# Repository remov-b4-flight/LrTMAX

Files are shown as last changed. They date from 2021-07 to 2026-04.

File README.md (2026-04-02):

# LrTMAX
Adobe Lightroom MIDI Developer Controller project (STM32F072Cx based)  
LrTMAX MIDI controller is formed by embedded hardware circuit board and its firmware.  
It used with [MIDI2LR](https://github.com/rsjaffe/MIDI2LR) software,  
You can control development parameters on RAW/JPEG photos.  
## Video(in brother project LrE-6)
  
detailed Video on [YouTube (LrE-6)](https://www.youtube.com/watch?v=oeDpP1sG9_Y)  
## Photo
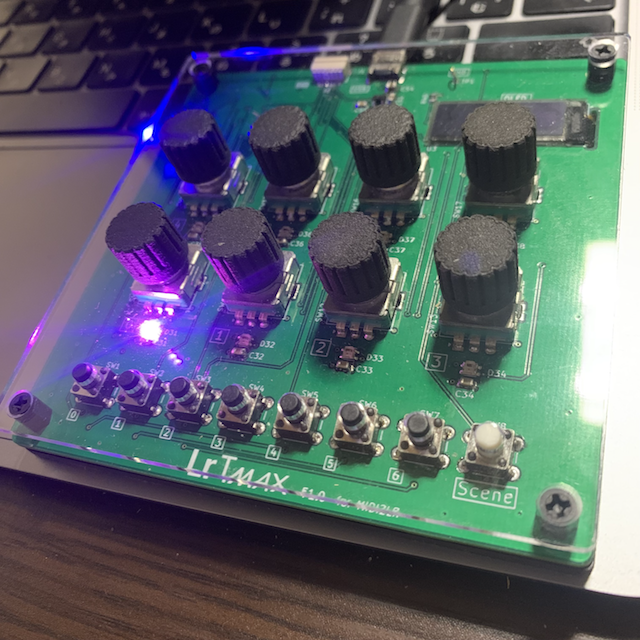
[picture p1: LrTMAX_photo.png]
  
LrTMAX is near to [LrE-6](https://github.com/remov-b4-flight/LrE-6)  
Information related Build,Configure & Use are exists on wiki.  
***
"Lightroom Classic" is Registerd Trademark of Adobe Corporation.

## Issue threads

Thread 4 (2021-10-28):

connection bitmap の描画

remov-b4-flight, 2021-10-28:
connection bitmapの描画、バージョン番号の部分の描画が正しく無い場合がある。
毎度違うパターンでおかしい。正しく描いている時もある。
絵の部分は正常

remov-b4-flight, 2021-10-29:
個別に描かせると正常

remov-b4-flight, 2021-11-01:
Still issue exists

remov-b4-flight, 2021-11-01:
明が暗に転ぶドットばかり
暗が明に転ぶドットはない。
絵の部分は正常

remov-b4-flight, 2021-11-02:
> 個別に描かせると正常

そういう訳でもないみたい。

remov-b4-flight, 2021-11-02:
Issue seems to be fixed.

Closed 2021-11-02.

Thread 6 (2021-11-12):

エンコーダーの動作が一瞬逆向きになる

remov-b4-flight, 2021-11-12:
まだエンコーダー0でしか試してないが動かした向きと逆に認識されてしまう場合がある

remov-b4-flight, 2021-11-13:
エンコーダー波形見るとチャッタリングしている。22nFでは除去仕切れないか。

remov-b4-flight, 2021-11-14:
エンコーダー0だけ100nFに交換して様子見。

remov-b4-flight, 2021-11-14:
Fixed in 0.55

remov-b4-flight, 2022-09-25:
チャタリングではなくエンコーダの機械的損耗でどちらのクリックに止まるか不安定な区間があり、結果短時間で信号の遷移が起こってしまう。

remov-b4-flight, 2022-09-25:
Fixed by 0.61

remov-b4-flight, 2022-09-25:
> エンコーダー0だけ100nFに交換して様子見。

反応悪くなる副作用あるので戻す。

Closed 2021-11-14.

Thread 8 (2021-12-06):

「現像」タブに移ると操作を反映しない

remov-b4-flight, 2021-12-06:
シーンスイッチで現像に移るよう設定すると移ったあと直後もしくは数十回の操作で操作を反映しなくなる。

remov-b4-flight, 2021-12-06:
MIDI2LR.appの設定で「現像に移る」を「未割り当て」に設定すれば停止しなくなるとでMIDI2LR側が問題ある可能性がある。

remov-b4-flight, 2021-12-06:
LEDとOLEDの表示には操作が反映されている。

remov-b4-flight, 2021-12-06:
USBの抜き差しまで機能が回復することはない。

remov-b4-flight, 2021-12-06:
開発マシンでMIDIMonitor.app使うとシーン切り替えボタンの後もMIDIメッセージを送り続けている。

remov-b4-flight, 2021-12-11:
MIDI2LR.appで「Lightroomへ送信を停止」すると、止まらない。やはりMIDI2LR側の問題か。

remov-b4-flight, 2021-12-11:
> MIDI2LR.appの設定で「現像に移る」を「未割り当て」に設定すれば停止しなくなるのでMIDI2LR側が問題ある可能性がある。

「未割り当て」でも停止してしまう。

remov-b4-flight, 2021-12-17:
Not issue on LrTMAX.

remov-b4-flight, 2021-12-30:
AKAI Synthstation25では起きないので、LrTMAXの何かが原因っぽい。

remov-b4-flight, 2021-12-31:
CCチャネル番号がNRPNの設定シーケンスで使用するチャンネルと被っているので40オフセットをつけて空き番号の空間に移動する。

remov-b4-flight, 2022-01-04:
Problem still exists.

remov-b4-flight, 2022-01-08:
0.57-4 seems to be fixed.

remov-b4-flight, 2022-01-10:
SynthStation25のMIDI descriptorをコピーしたら解決したようだ。

remov-b4-flight, 2023-06-29:
nanooKontrol2ベースにしたら再発した(?)

remov-b4-flight, 2023-06-29:
> USBの抜き差しまで機能が回復することはない。

ファームウェアリブートまで機能が回復する事はない。

remov-b4-flight, 2023-07-01:
アクティビティモニター 反応ある間は送信パケットの数値が操作とともに上がっていくが、症状が出ると上がらなくなる。

remov-b4-flight, 2023-07-01:
> アクティビティモニター 反応ある間は送信パケットの数値が操作とともに上がっていくが、症状が出ると上がらなくなる。

と、言うことは問題はMIDI2LR.Appか。

remov-b4-flight, 2023-07-03:
MIDI2LR.app ソース解析の結果、
CC チャンネル 6,38,98,99は
NRPNの処理用に個別の判断の判断があるため、使用を避ける。
CC 40(decimal)をシーン0、エンコーダ0のチャンネルとする。

remov-b4-flight, 2023-07-04:
問題が発生する「部分補正 テクスチャ」と「部分補正 明瞭度」についてもマスクを作る前なら問題なく何回でも操作できる。

remov-b4-flight, 2023-07-04:
> 問題が発生する「部分補正 テクスチャ」と「部分補正 明瞭度」についてもマスクを作る前なら問題なく何回でも操作できる。

ということはLrTMAXには何の問題もない(?)

remov-b4-flight, 2023-07-18:
現像調整をしているファイルに移るとCCコマンドを受信して現在値を反映するが、これを受信した後反映しなくなる

remov-b4-flight, 2023-07-18:
usbd_midi.c を見ると MidiRx()を呼んだ後、
USBD_LL_PrepareReceive()を呼んでいる。
この部分に時間がかかる事は障害になると考え、
Midi_Rx内でキューイングを行うようにした。

remov-b4-flight, 2023-07-18:
キューイングされたデータはEmulate MIDI 内で処理して、
MIDI_CC_Value[] に反映している事までを確認した。

remov-b4-flight, 2023-07-18:
ただし、MIDI_CC_Value[] の反映を行ったあと、送信データが反映されない。か、ピッチベンドとして解釈されてしまう。

remov-b4-flight, 2023-07-19:
MIDI2LR.Appからの受信で何か起きるようだ。
ブランチMidiRXで作業中

remov-b4-flight, 2023-07-19:
データを受信したあと、全く送信していないわけでは無く、操作に応じた送信自体は続いている。

remov-b4-flight, 2023-07-19:
調整が一つなら止まらない。4つは確実に止まってしまう。

remov-b4-flight, 2023-07-22:
現像タブ上でも、ゆっくりした操作なら、止まらない。
ライブラリタブなら止まらない。

remov-b4-flight, 2023-07-23:
0.67で部分的に解決

remov-b4-flight, 2023-07-27:
0.67の解決はプロジェクト全体に-Ofastを指定さた物だったが
エンコーダーの向きが逆開店に認識される副作用が発生する様だ。
-O3なら発生しない模様。

remov-b4-flight, 2023-07-28:
> 0.67の解決はプロジェクト全体に-Ofastを指定さた物だったが
> エンコーダーの向きが逆開店に認識される副作用が発生する様だ。
> -O3なら発生しない模様。

-O3でも発生してしまう。-O2は出ない

remov-b4-flight, 2023-07-31:
#19 の問題を解決したら逆向きは軽減した 最適化は-O2で固定

remov-b4-flight, 2023-08-19:
#19 の根本的解決でキューイングを改良したのでこのissueに関してもすこしはよくなっている事を期待する。

remov-b4-flight, 2023-08-19:
現像ずみ写真のコレクションをカーソルキーで辿っていっても止まらない。
エンコーダーの操作でのみ停止する。

remov-b4-flight, 2023-08-19:
受信しつつでも送信はしている様だ。

remov-b4-flight, 2023-08-19:
ゆっくり操作、特に現像履歴がアクティブになった後まで待ってエンコーダを動かすと、止まらない。

remov-b4-flight, 2023-08-21:
自家ビルドしたMIDI2LR Appでログとかブレークポイントを張った結果、現象が起きている時はMidiReceiverに制御が来ていない、
juicerで止まっている

remov-b4-flight, 2023-08-25:
0.69で止まらなくなった。対策完了？

Closed 2023-08-25.

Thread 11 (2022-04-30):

CC78[64]なモードに入ってしまう。

remov-b4-flight, 2022-04-30:
突然 Control Channel=78 value=64しか送らないモードに入ってしまう。
きっかけは Scene0 ENC0の操作っぽい。 それ以降どの操作でもCC 78[64]を送るようだ。
電源再投入まで復帰せず。

remov-b4-flight, 2022-04-30:
そんなに頻繁な発生ではない。

remov-b4-flight, 2022-05-22:
CC[90]= 40というパターンもある。
OLEDの表示は正常。

Closed 2023-05-18.

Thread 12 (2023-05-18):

反応が無くなる

remov-b4-flight, 2023-05-18:
正常に操作していた後、しばらく放置しておくと
操作してもMIDI2LRアプリの反応がなくなる。
「再読み込み」で戻ってくる場合が殆どだが、戻ってこない場合もある。
macOSでのみ確認

remov-b4-flight, 2023-06-20:
場当たり的な対策としてSW1とSW8 (Undoと Scene)を同時押しする事でパワーオンリセット実行する様変更

remov-b4-flight, 2023-06-29:
#8 と原因同じかもしれないのでそちらで議論続ける。

Closed 2023-06-29.

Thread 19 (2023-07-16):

消耗でチャッターが酷くなる可能性

remov-b4-flight, 2023-07-16:
「次の写真-前の写真」に設定しているENC0だけチャッターと思われる逆方向に進んでしまう現象が頻発している。
- 問題はENC0だけ(使用頻度が極めて高い)
- ENC7に「次ー前」を設定しても現象出ない
- 問題は黒基板の運用機のみ。

remov-b4-flight, 2023-07-16:
#6 と重複かもしれない。

remov-b4-flight, 2023-07-16:
ENC0だけ33nFに替えてみる。

remov-b4-flight, 2023-07-16:
> ENC0だけ33nFに替えてみる。

確かにENC0だけチャッターがひどい波形になってる。

remov-b4-flight, 2023-07-17:
実験機(緑基板)も33nに交換する。

remov-b4-flight, 2023-07-18:
公開の回路図、BOMも33nで変更する。

remov-b4-flight, 2023-07-28:
チャッターも起きてはいるだろうが頻度が酷い。デバッグビルドでは軽減される(チャッターだけになる？)ので最適化が問題を引き起こしている可能性

remov-b4-flight, 2023-07-30:
TIM15のチャッター対策用のタイマーの設定値がひどい値だった。
0.67-11にて2mSに修正済み。

remov-b4-flight, 2023-08-01:
ENCの動きが止まった時にCC受信して、
値がMedian付近に居る時の方が
逆回転やチラつきなどの意図しない動きが少ない。

remov-b4-flight, 2023-08-12:
0.68で対応

remov-b4-flight, 2023-08-16:
MIDI2LRのソースより
変更量が正なら次へ、負なら前へ
`void LrIpcOut::MidiCmdCallback(rsj::MidiMessage mm)
略
                  if (const auto change {controls_model_.MeasureChange(mm)}; change > 0) {
                     SendCommand(a->second.first); /* turned clockwise */
                  }
                  else if (change < 0) {
                     SendCommand(a->second.second); /* turned counterclockwise */
                  }
略
`

remov-b4-flight, 2023-08-19:
やはりキューイングで止まっていた。
0.68-5で対応済み。

Closed 2023-08-19.

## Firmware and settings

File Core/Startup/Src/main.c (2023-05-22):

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
/* Includes ------------------------------------------------------------------*/
#include "main.h"
#include "usb_device.h"

/* USER CODE BEGIN Includes */
#include <stdbool.h>
#include "LrCommon.h"
#include "midi.h"
#include "led.h"
#include "bitcount.h"
#include "key_define.h"
#include "usbd_midi_if.h"
#include "ssd1306.h"
/* USER CODE END Includes */

/* USER CODE BEGIN PD */
#ifdef DEBUG
#define CONN_MSG_D	"%s %2x.%02xD"
#else
#define CONN_MSG	"%2x.%02x"
#endif

#define CC_MSG_3DG	"C%3d = %3d    S%1d"
#define CC_MSG_2DG	"Ch%1d = %3d    S%1d"
#define SPACE_CHAR  ' '

#define DFU_MSG	"DFU Bootloader."
#define SYSTEM_MEMORY	0x1FFFC800
#define SWMASK	0x0F
#define SW1_MASK	1
#define SW3_MASK	4
//! deine Key combination to invoke reset
#define RESET_KEY_PATTERN	0x81	//[Undo]+[Scene]

/* USER CODE END PD */

I2C_HandleTypeDef hi2c2;
DMA_HandleTypeDef hdma_i2c2_tx;

TIM_HandleTypeDef htim1;
TIM_HandleTypeDef htim3;
TIM_HandleTypeDef htim6;
TIM_HandleTypeDef htim7;
TIM_HandleTypeDef htim14;
TIM_HandleTypeDef htim15;
DMA_HandleTypeDef hdma_tim3_ch1_trig;

/* USER CODE BEGIN PV */

//! STM32 TIM3 instance handle
TIM_HandleTypeDef htim3;
extern	USBD_HandleTypeDef hUsbDeviceFS;
extern PCD_HandleTypeDef hpcd_USB_FS;
//! Lr**** USB connection state
uint8_t		LrState;
//! Lr**** Scene index
uint8_t	LrScene;
// keyboard variable
//! If true, ISR detected any Key/Encoder was moved.
bool		isKeyPressed;
//! Key pressed/released status set by timer key scanning.
KEYSCAN	Key_Stat;
//! In key scanning whether Line selected to read for key matrix.
uint8_t	Key_Line;
//! If true, MIDI event previous sent is switch. if false, it's encoder
bool		isPrev_sw;
#if 0
//! Bit masks for which bit of KEYSCAN variable acts as key.
uint32_t	MaskKey[SCENE_COUNT];
//! Bit masks for which bit of KEYSCAN variable acts as encoder.
uint32_t	MaskEnc[SCENE_COUNT];
#endif
// OLED variables
//! Flag set by timer ISR, It makes 'off' OLES contents.
bool 		Msg_Timer_Update;
//! Timer counter ticked by TIM7.
int32_t	Msg_Timer_Count;
//! If true Msg_Timer counting is enabled.
bool	Msg_Timer_Enable;
//! If true, Screen is cleared in main() that is determined on timer interrupt.
bool	Msg_Off_Flag;
//! If true, Screen is flashed by Msg_Buffer[] at main() function.
static	bool	isMsgFlash;
//! If true, frame_buffer[] contents flashes the screen.
static	bool	isRender;

// LED variables
//! If true, LEDs are flashed by LEDColor[] array.
bool	isLEDsendpulse;
//! Flag is set by timer ISR, It makes LED_Timer[] count up in main()
bool	LED_Timer_Update;

// Scene related
extern	KEY_DEFINE	keytable[SCENE_COUNT][DEFINES_PER_SCENE];
extern	char 		*scene_name[SCENE_COUNT];
extern	uint8_t	led_axis_table[DEFINES_PER_SCENE];

extern	uint8_t	LED_Scene[SCENE_COUNT][LED_COUNT];
extern	uint8_t	LEDColor[LED_COUNT];
extern	uint8_t	LEDTimer[LED_COUNT];

//! String message buffer of screen
extern char Msg_Buffer[MSG_LINES][MSG_WIDTH + 1];

// MIDI variables
//! MIDI CC message value for each channels.
uint8_t MIDI_CC_Value[SCENE_COUNT][ENC_COUNT];
//! keep previous sent 'Key On' note/channel for release message.
uint8_t prev_note;
//! Instance Handle of USB interface
extern USBD_HandleTypeDef *pInstance;

/* USER CODE END PV */

void SystemClock_Config(void);
static void MX_GPIO_Init(void);
static void MX_DMA_Init(void);
static void MX_TIM3_Init(void);
static void MX_TIM1_Init(void);
static void MX_TIM14_Init(void);
static void MX_I2C2_Init(void);
static void MX_TIM7_Init(void);
static void MX_TIM6_Init(void);
static void MX_TIM15_Init(void);
/* USER CODE BEGIN 0 */

/**
 * @brief jump into system memory (DFU bootloader)
 */
void Jump2SystemMemory() {
	void (*SysMemBootJump)(void);

	/*
	* Set system memory address.
	* For STM32F072, system memory is on 0x1FFFC800
	*/
	volatile uint32_t addr = SYSTEM_MEMORY;
	/**
	 * Stop all Interrupt source
	 */
	//TIM1
	TIM1->DIER = 0;
	TIM1->SR = 0;
	//TIM6
	TIM6->DIER = 0;
	TIM6->SR = 0;
	//TIM7
	TIM7->DIER = 0;
	TIM7->SR = 0;
	//EXTI
	EXTI->IMR = 0;
	EXTI->PR = 0;
	//DMA
	DMA1->IFCR = 0;
	//I2C2
	I2C2->ICR = 0;
	//USB
	USB->ISTR = 0;
	// Disable systick timer and reset it to default values
	SysTick->CTRL = 0;
	SysTick->LOAD = 0;
	SysTick->VAL = 0;

	// Re-map system memory to address 0x0000 0000 in address space
	SYSCFG->CFGR1 = 0x01;

	// Set jump memory location for system memory
	// Use address with 4 bytes offset which specifies jump location where program starts
	SysMemBootJump = (void (*)(void)) (*((uint32_t *)(addr + 4)));

	// Set main stack pointer.
	uint32_t msp = *(uint32_t *)addr;
	__set_MSP(msp);

	/**
	 * Call our function to jump to set location
	 * This will start system memory execution
	 */
	SysMemBootJump();
}

/**
 *	@brief	Mask all EXTI lines of encoders
 */
static void Stop_All_Encoders(){
	uint32_t temp = EXTI->IMR;
	temp &= 0xffff0000;
	EXTI->IMR = temp;
}

/**
 * @brief	Release all EXTI lines masked by StopAllEncoders()
 */
static void Start_All_Encoders(){
	uint32_t temp = EXTI->IMR;
	temp |= 0x0000ffff;
	EXTI->IMR = temp;
}

static inline void Start_MsgTimer(uint32_t tick){
	Msg_Off_Flag = false;
	Msg_Timer_Count = tick;
	Msg_Timer_Enable = true;
}

static inline void Msg_Print(){
	isMsgFlash = true;
}

/**
 * @brief Make MaskKey[],MaskRot[] from keytable[](in key_define.c)
 * @return false : there is some configuration error.
 */
static void	MakeMasks(){
#if 1
#else
	for(uint8_t scn = 0; scn < SCENE_COUNT; scn++){
		for(uint8_t bit = 0; bit < DEFINES_PER_SCENE; bit++){
			uint32_t	or_bit = (1 << bit);
			MaskKey[scn] |= (keytable[scn][bit].type == TYPE_SWITCH)?	or_bit : 0;
			MaskEnc[scn] |= (keytable[scn][bit].type == TYPE_ROTARY)?	or_bit : 0;
		}
	}
#endif
}
/**
 * @brief start/stop matrix L0-L3 control
 */
static void matrix_control(uint8_t control) {
	HAL_GPIO_WritePin(L0_GPIO_Port, L0_Pin, (control == Lr_MATRIX_START)? GPIO_PIN_SET : GPIO_PIN_RESET);
	HAL_GPIO_WritePin(L1_GPIO_Port, L1_Pin, GPIO_PIN_RESET);
	HAL_GPIO_WritePin(L2_GPIO_Port, L2_Pin, GPIO_PIN_RESET);
	HAL_GPIO_WritePin(L3_GPIO_Port, L3_Pin, GPIO_PIN_RESET);
}
/**
 *	@brief	Generate MIDI event and Send to host by User interaction.
 *	@return true : function processed any Key/Encoder event.
 *	@pre	isKeyPressed	any key is pressed or not
 *	@pre	Key_Stat		current key status
 */
static void EmulateMIDI() {
	//! USB MIDI message structure for send
	MIDI_EVENT	USBMIDI_TxEvent;

	if (isKeyPressed) {
		char 		msg_string[MSG_WIDTH + 1];
		uint8_t		bitpos = ntz32(Key_Stat.wd);
		uint32_t	rkey = (Key_Stat.wd);
		bool 		isKeyReport = false;

		if ( Key_Stat.wd & MASK_KEY ) { //Check Matrix switches
			//Send 'Note On' Event from key matrix
			uint8_t	note = (LrScene * NOTES_PER_SCENE) + bitpos;
			if (Key_Stat.wd == RESET_KEY_PATTERN) {
				HAL_NVIC_SystemReset();
			}else if (bitpos == SCENE_BIT) { //is [SCENE] switch pressed?
			   	//Move to next Scene.
				if((++LrScene) >= SCENE_COUNT){
					LrScene = Lr_SCENE0;
				}
				LED_SetScene(LrScene);
				strcpy(msg_string, scene_name[LrScene]);
			}else{
				LED_SetPulse(keytable[LrScene][bitpos].axis, keytable[LrScene][bitpos].color, keytable[LrScene][bitpos].period);
				sprintf(msg_string, "Note: %3d    S%1d", note, (LrScene % SCENE_COUNT) );
			}
			isKeyReport = true;

			//Print Message to OLED & LED
			if (keytable[LrScene][bitpos].message != NULL) {
				SSD1306_SetScreen(ON);

				strcpy(Msg_Buffer[0], keytable[LrScene][bitpos].message);
				strcpy(Msg_Buffer[1], msg_string);
				Msg_Print();

				Start_MsgTimer(MSG_TIMER_DEFAULT);
			}

			if (isKeyReport == true) {
				//Set 'Note ON
				USBMIDI_TxEvent.header = MIDI_NT_ON;
				USBMIDI_TxEvent.status = MIDI_NT_ON_S;
				USBMIDI_TxEvent.channel = note;
				USBMIDI_TxEvent.value = MIDI_NT_VELOCITY;

				prev_note = note;
				isPrev_sw = true;
			}
		}else if( Key_Stat.wd & MASK_ENC ) { //Check encoder's move
			//Send CC Event from encoder
			uint8_t axis = (bitpos - KEY_COUNT) / 2;
			uint8_t val = MIDI_CC_Value[LrScene][axis];
			uint8_t channel = CC_CH_OFFSET + (LrScene * CC_CH_PER_SCENE) + axis;

			USBMIDI_TxEvent.header = MIDI_CC_HEADER;
			USBMIDI_TxEvent.status = MIDI_CC_STATUS;
			USBMIDI_TxEvent.channel = channel;
			USBMIDI_TxEvent.value = val;

			isPrev_sw = false;

			//Print Message to OLED & LED
			if (keytable[LrScene][bitpos].message != NULL) {
				SSD1306_SetScreen(ON);
				sprintf(msg_string,
					((channel > 99)? CC_MSG_3DG : CC_MSG_2DG), channel, val, LrScene);
				strcpy(Msg_Buffer[0], keytable[LrScene][bitpos].message);
				strcpy(Msg_Buffer[1], msg_string);
				Msg_Print();

				Start_MsgTimer(MSG_TIMER_DEFAULT);
			}
			LED_SetPulse(keytable[LrScene][bitpos].axis, keytable[LrScene][bitpos].color, keytable[LrScene][bitpos].period);
			isKeyReport = true;

		} else if (isPrev_sw == true && rkey == 0) {// Switch is released
			//Send 'Note Off' Event
			USBMIDI_TxEvent.header = MIDI_NT_OFF;
			USBMIDI_TxEvent.status = MIDI_NT_OFF_S;
			USBMIDI_TxEvent.channel = prev_note;
			USBMIDI_TxEvent.value = MIDI_NT_VELOCITY;

			isKeyReport = true;
			isPrev_sw = false;
		}

		if (isKeyReport == true) {
			//Send MIDI event via USB
			USBD_LL_Transmit (pInstance, MIDI_IN_EP, (uint8_t *)&USBMIDI_TxEvent, MIDI_EVENT_LENGTH);
			isKeyReport = false;
		}

		/* Clear the switch pressed flag */
		isKeyPressed = false;
	}
}
/* USER CODE END 0 */

/**
  * @brief  The application entry point.
  * @retval int
  */
int main(void)
{
  /* USER CODE BEGIN 1 */
	//! Indicates 1st Msg_Timer timeout has occurred from power on reset.
	bool Msg_1st_timeout = true;
  /* USER CODE END 1 */

  /* MCU Configuration--------------------------------------------------------*/

  /* Reset of all peripherals, Initializes the Flash interface and the Systick. */
  HAL_Init();

  /* USER CODE BEGIN Init */
	Key_Line = L0;
	Msg_Off_Flag = false;
	Msg_Timer_Enable = false;
	Msg_Timer_Count = MSG_TIMER_DEFAULT;
	isMsgFlash = false;
	isRender = true;

	LrState = LR_RESET;
	LrScene = Lr_SCENE0;

	isPrev_sw = false;
	isLEDsendpulse = false;
	Msg_Timer_Update = false;
	LED_Timer_Update = false;
  /* USER CODE END Init */

  /* Configure the system clock */
  SystemClock_Config();

  /* Initialize all configured peripherals */
  MX_GPIO_Init();
  MX_DMA_Init();
  MX_TIM3_Init();
  MX_TIM1_Init();
  MX_TIM14_Init();
//MX_USB_DEVICE_Init();
  MX_I2C2_Init();
  MX_TIM7_Init();
  MX_TIM6_Init();
  MX_TIM15_Init();
  /* USER CODE BEGIN 2 */
	//Stop All Encoders until USB link up
	Stop_All_Encoders();
	//Initialize Switch matrix
	HAL_GPIO_WritePin(L0_GPIO_Port, L0_Pin, GPIO_PIN_SET);	//Initialize L0-3.
	MakeMasks();

	//Initialize series of WS2812C
	GPIOA->PUPDR |= GPIO_PUPDR_PUPDR6_0;	//Pull up PA6 (WS2812C-2020 workaround)
	GPIOA->ODR |= GPIO_PIN_6;				//'RESET' state
	//AF -> GPIO
	GPIOA->MODER &= ~(GPIO_MODER_MODER6_1);
	GPIOA->MODER |=	GPIO_MODER_MODER6_0;

	LED_Initialize();						//Set all LEDs to 'OFF'

	//Initialize SSD1306 OLED
	HAL_Delay(SSD1306_PWRUP_WAIT);		//Wait for OLED module power up.
	SSD1306_Initialize();
  /* USER CODE END 2 */

  /* Infinite loop */
  /* USER CODE BEGIN WHILE */
	uint32_t	nc_count = 0;

	HAL_TIM_Base_Start_IT(&htim6);		//Start LED timer.
	HAL_TIM_Base_Start_IT(&htim7);		//Start Message timer.
	Start_MsgTimer(MSG_TIMER_DEFAULT);
	LrState = LR_USB_NOLINK;

	//Check SW1 and SW3 at Power On
	if ((GPIOA->IDR & SWMASK) == (SW1_MASK | SW3_MASK)) {
		LrState = LR_USB_DFU;
	} else {
		MX_USB_DEVICE_Init();
	}

	//Initialize CC Value table
	memset(MIDI_CC_Value, MIDI_CC_INITIAL, CC_COUNT);

	//LED Initialize
	LED_SetScene(LrScene);

	//Main loop
	while (1) {
	if (LrState == LR_USB_LINKUP) {
		//USB device configured by host
		SSD1306_SetScreen(ON);

		matrix_control(Lr_MATRIX_START);		//Initialize L0-3.
		HAL_TIM_Base_Start_IT(&htim1);		//Start Switch matrix timer.

		htim15.Instance->CNT = TIM_PERIOD_DCHAT;
		HAL_TIM_Base_Start(&htim15);      //Start De-chatter timer.
		Start_All_Encoders();				//Start rotary encoder.

#ifdef DEBUG
		sprintf(Msg_Buffer[0], CONN_MSG_D, Lr_PRODUCT, USBD_DEVICE_VER_MAJ, USBD_DEVICE_VER_MIN);
		memset(Msg_Buffer[1], (int)SPACE_CHAR, MSG_WIDTH );
		Msg_Print();
#else
		SSD1306_LoadBitmap();
		sprintf(Msg_Buffer[0], CONN_MSG, USBD_DEVICE_VER_MAJ, USBD_DEVICE_VER_MIN);
		SSD1306_RenderBanner(Msg_Buffer[0], 88, 16);
		SSD1306_FlashScreen();
#endif
		Start_MsgTimer(MSG_TIMER_DEFAULT);
		memcpy(LEDColor,LED_Scene[LrScene],LED_COUNT);
		LED_SetPulse(LED_IDX_ENC0, LED_PINK, LED_TIM_CONNECT);
		LrState = LR_USB_LINKED;

	} else if (LrState == LR_USB_LINKED) {
		//Operate as MIDI Instruments.
		EmulateMIDI();
	} else if (LrState == LR_USB_LINK_LOST) {
		LrScene	= Lr_SCENE0;
		Stop_All_Encoders();

		HAL_TIM_Base_Stop(&htim1);
		matrix_control(Lr_MATRIX_STOP);		//Stop L0-L3

		LED_TestPattern();
		Msg_1st_timeout = false;
		Start_MsgTimer(MSG_TIMER_DEFAULT);
		nc_count = 0;
		LrState = LR_USB_NOLINK;

	} else if (LrState == LR_USB_NOLINK) {
		//USB can't be configured or disconnected by host.
		if (Msg_Off_Flag == true) {
			if (Msg_1st_timeout == true) {
				LrState = LR_USB_LINK_LOST;
			} else { // 2nd or more
				sprintf(Msg_Buffer[0], "%12ld", nc_count++);
				SSD1306_SetScreen(ON);

				Msg_Print();

				//Restart OLED timer.
				Start_MsgTimer(MSG_TIMER_NOLINK);

				//Rotate LED colors
				uint8_t	tempcolor = LEDColor[7];
				LEDColor[7] = LEDColor[6];
				LEDColor[6] = LEDColor[5];
				LEDColor[5] = LEDColor[4];
				LEDColor[4] = LEDColor[3];
				LEDColor[3] = LEDColor[2];
				LEDColor[2] = LEDColor[1];
				LEDColor[1] = LEDColor[0];
				LEDColor[0] = tempcolor;

				isLEDsendpulse = true;
			}
		}// Msg_Off_Flag
	} else if (LrState == LR_USB_DFU) {
		if (Msg_Off_Flag == true) {
			if (nc_count == 0){
				strcpy(Msg_Buffer[0], DFU_MSG);
				SSD1306_SetScreen(ON);
				Msg_Print();
				nc_count++;
			}else if(nc_count == 1){
				LED_TestPattern();
				nc_count++;
			}else if (nc_count <= 2){
				LED_Initialize();
				Jump2SystemMemory();
			}
			Start_MsgTimer(MSG_TIMER_NOLINK/2);
		}

	}// LrState

	//LED Timer
	if (LED_Timer_Update == true) { //24ms interval
		for (uint8_t i = 0; i < LED_COUNT; i++){
			if (LEDTimer[i] != LED_TIMER_CONSTANT && --LEDTimer[i] == 0) {
				LED_SetPulse(i, LED_Scene[LrScene][i], LED_TIMER_CONSTANT);
			}
		}
		LED_Timer_Update = false;
		continue;
	}

	//Flashing LEDs
	if (isLEDsendpulse == true) {
		if (LED_SendPulse() == true) {
			isLEDsendpulse = false;
		} else {
			HAL_Delay(LED_TIM_RETRY_WAIT);	// i2c is busy, retry with interval
		}
		continue;
	}

	//OLED timer
	if (Msg_Timer_Update == true) {	//32.7ms interval
		if (Msg_Timer_Enable == true && (--Msg_Timer_Count) <= 0) {
			Msg_Timer_Enable = false;
			Msg_Off_Flag = true;
		}
		Msg_Timer_Update = false;
		continue;
	}

	//OLED off Timer
	if (Msg_Off_Flag == true) {
		Msg_Off_Flag = false;
		SSD1306_SetScreen(OFF);
		SSD1306_ClearBuffer();
		continue;
	}

	//Flashing OLED.
	if (isMsgFlash == true) {
		if (isRender == true) {
			SSD1306_Render2Buffer();
			isRender = false;
		}
		if (SSD1306_FlashScreen() == true) {
			isMsgFlash = false;	// success to flash
			isRender = true;
		} else {
			HAL_Delay(I2C_RETRY_WAIT);	// i2c is busy, retry with interval
		}
		continue;
	}
#if 0
	HAL_PWR_EnterSLEEPMode(PWR_LOWPOWERREGULATOR_ON, PWR_SLEEPENTRY_WFI);
#endif
  /* USER CODE END WHILE */

  /* USER CODE BEGIN 3 */
  }
  /* USER CODE END 3 */
}

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


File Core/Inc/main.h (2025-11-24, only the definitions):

#define USBD_DEVICE_VER	0x0074
#define SPACE_CHAR  ' '
#define TIM_PERIOD_NPIX 279
#define Lr_PRODUCT "LrTMAX"
#define PWM_HI 38
#define TIM_PERIOD_RGBLED 24576
#define PWM_LO 15
#define PWM_PERIOD 59
#define Lr_PID 0xA380
#define TIM_PERIOD_ENC 1600
#define TIM_PRESC_100uS 4799
#define Lr_VENDOR "Ruffles Inc."
#define TIM_PRESC_1uS 47
#define TIM_PERIOD_MATRIX 7999
#define TIM_PERIOD_OLED 32767
#define ENC5B_Pin GPIO_PIN_13
#define ENC5B_GPIO_Port GPIOC
#define ENC3A_Pin GPIO_PIN_14
#define ENC3A_GPIO_Port GPIOC
#define ENC3B_Pin GPIO_PIN_15
#define ENC3B_GPIO_Port GPIOC
#define ENC4A_Pin GPIO_PIN_0
#define ENC4A_GPIO_Port GPIOF
#define ENC4B_Pin GPIO_PIN_1
#define ENC4B_GPIO_Port GPIOF
#define M0_Pin GPIO_PIN_0
#define M0_GPIO_Port GPIOA
#define M1_Pin GPIO_PIN_1
#define M1_GPIO_Port GPIOA
#define M2_Pin GPIO_PIN_2
#define M2_GPIO_Port GPIOA
#define M3_Pin GPIO_PIN_3
#define M3_GPIO_Port GPIOA
#define ENC0A_Pin GPIO_PIN_4
#define ENC0A_GPIO_Port GPIOA
#define ENC0B_Pin GPIO_PIN_5
#define ENC0B_GPIO_Port GPIOA
#define LED_DON_Pin GPIO_PIN_6
#define LED_DON_GPIO_Port GPIOA
#define ENC6A_Pin GPIO_PIN_2
#define ENC6A_GPIO_Port GPIOB
#define ENC2A_Pin GPIO_PIN_10
#define ENC2A_GPIO_Port GPIOB
#define ENC2B_Pin GPIO_PIN_11
#define ENC2B_GPIO_Port GPIOB
#define ENC5A_Pin GPIO_PIN_12
#define ENC5A_GPIO_Port GPIOB
#define SCL_Pin GPIO_PIN_13
#define SCL_GPIO_Port GPIOB
#define SDA_Pin GPIO_PIN_14
#define SDA_GPIO_Port GPIOB
#define L0_Pin GPIO_PIN_9
#define L0_GPIO_Port GPIOA
#define L3_Pin GPIO_PIN_10
#define L3_GPIO_Port GPIOA
#define USB_DM_Pin GPIO_PIN_11
#define USB_DM_GPIO_Port GPIOA
#define USB_DP_Pin GPIO_PIN_12
#define USB_DP_GPIO_Port GPIOA
#define SWDIO_Pin GPIO_PIN_13
#define SWDIO_GPIO_Port GPIOA
#define SWCLK_Pin GPIO_PIN_14
#define SWCLK_GPIO_Port GPIOA
#define ENC6B_Pin GPIO_PIN_3
#define ENC6B_GPIO_Port GPIOB
#define L1_Pin GPIO_PIN_4
#define L1_GPIO_Port GPIOB
#define L2_Pin GPIO_PIN_5
#define L2_GPIO_Port GPIOB
#define ENC7A_Pin GPIO_PIN_6
#define ENC7A_GPIO_Port GPIOB
#define ENC7B_Pin GPIO_PIN_7
#define ENC7B_GPIO_Port GPIOB
#define ENC1A_Pin GPIO_PIN_8
#define ENC1A_GPIO_Port GPIOB
#define ENC1B_Pin GPIO_PIN_9
#define ENC1B_GPIO_Port GPIOB
#define LED_TIM_RETRY_WAIT	21		//Transfer period for I2C
#define I2C_RETRY_WAIT		2		//Transfer period for TIM3 PWM
#define DFU_MSG	"DFU Bootloader."
#define SW1_MASK	1
#define SW3_MASK	4
#define SWMASK	(SW1_MASK | SW3_MASK)

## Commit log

2021-05-24 1st Commit
    [KNOB1.FCStd, KNOB12.FCStd, LrE-6.dsn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]
2021-05-25 Fix panels
    [LrTMAX.kicad_pcb, LrTMAX_panel.kicad_pcb]
2021-05-25 Add back panel
    [LrTMAX_BOTTOM.kicad_pcb, LrTMAX_TOP.kicad_pcb, LrTMAX_panel.kicad_pcb]
2021-05-30 Board fixes
    [LrTMAX.kicad_pcb, LrTMAX_BOTTOM.kicad_pcb]
2021-06-03 Panel ordered.
    [LrTMAX_BOTTOM.kicad_pcb, LrTMAX_TOP.kicad_pcb]
2021-06-04 Board fix
    [LrTMAX.kicad_pcb]
2021-06-06 fix typo
    [LrTMAX.kicad_pcb]
2021-06-12 Add BOM
    [LrTMAX.BOM.csv]
2021-06-20 0.46-1
    Reflact board debug.
    [LrTMAX.kicad_pcb]
2021-06-28 0.46-3
    Adjust LED PWM width to meed WS2812-2020 spec.
    [LrTMAX.BOM.csv, LrTMAX.sch]
2021-07-03 0.46-4
    Fix EXTI routine for ENC3.
    (and first modify for F1.2 board)
    [LrTMAX.kicad_pcb]
2021-07-03 0.46-4
    fix some comments & key defines.
    [key_define.c, led.c, led.h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]
2021-07-05 0.46-6
    LrTMAX.4lpb modify.
    [LrTMAX.BOM.csv, LrTMAX.kicad_pcb]
2021-07-06 0.46-6
    Board F1.2 order.
    [LrTMAX.kicad_pcb, LrTMAX_BOTTOM.kicad_pcb, LrTMAX_TOP.kicad_pcb]
2021-07-06 0.46-7
    F1.2 board order
2021-07-08 0.47-1
    fix current in USB descriptor.
2021-07-12 0.47-5
    some Debug tweak.
    [LrTMAX.BOM.csv, LrTMAX.sch]
2021-07-15 Add Documents
    [WS2812C-2020.xls]
2021-07-19 0.47-9
    Fix DMA Alignment
    [LrTMAX.ioc, led.c]
2021-07-19 0.47-9
    Fix Scene LED pattern.
    [led.c, main.c]
2021-07-22 0.47-11
    some refactoring,fixes, workarounds.
    [led.c, main.c, main.h]
2021-07-23 0.47-12
    LED fixing intermidiate.
    [led.c, main.c]
2021-07-23 0.47-13
    LED fixing completed.
    [led.c, main.c]
2021-07-23 0.48-1
    Fix for I2C on Release build not work.
2021-08-15 0.48-4
    Adjust LED pink color.
    [LrTMAX.BOM.csv]
2021-10-07 0.49-pre6m
    move to F0_11.3
    [LrTMAX.BOM.csv, LrTMAX.kicad_pcb, LrTMAX.sch]
2021-10-14 0.49c
    USB conn. changed to typeC
    [LrTMAX.kicad_pcb, LrTMAX.sch]
2021-10-16 0.49c-2
    ADC stopped.
2021-10-21 0.49c-3
    KiCAD library resrore & ENC5 ISR routine.
    [LrTMAX.BOM.csv, LrTMAX.sch, WS2812C-2020.xls]
2021-10-21 0.49c-4
    Fix issue #1 (Remove HAL_TIM_Base_Init(&htim14) from Delay_us() )
    [main.c]
2021-10-22 0.51
    version feeding (avoid LrE-6 conflict)
    [main.h]
2021-10-27 0.51-9
    Move Delay_us() to led.c (related with #1)
2021-10-27 0.51-11
    issue #3 adopted.
    [main.c]
2021-10-28 0.51-12
    Change Licence to "3-clause BSD".
    Create 'bitmapmaker.xls' OLED bitmap generator.
    Fix version display in Debug build.
    [bitmapmaker.xls]
2021-10-29 0.52-2
    Fix ssd1306 rendering.
    [main.c]
2021-10-29 0.52-3
    Fix comments still describe as 'LrE-6'
    and issue #4 as closed
    [key_define.c, led.h, main.c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]
2021-10-29 0.52-4
    Fix comments & and remove unused function declaration in main.h .
    [key_define.c, main.c, main.h]
2021-11-01 0.53
    Use TIM7 for OLED Timer.
    Fix issue #2.
    Refactoring.
    [LrTMAX.ioc, key_define.c, led.c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]
2021-11-02 0.53-1
    Fix long MsgTimer interval
    Moved LED Timer TIM1 to TIM6
    Fix #5 (suspend TIM1 start until USB link up)
    [LrTMAX.ioc, main.c, main.h]
2021-11-02 0.53-2
    Fix connection bitmap
    [main.c]
2021-11-02 0.53-3
    Fix issue #4 by redesign connect bitmap,non-overlap with version
    display.
    [main.c]
2021-11-02 0.53-4
    Save design data
    [bitmapmaker.xls]
2021-11-09 0.54-1
    Fix batting LED lighting on USB connect.
    [bitmapmaker.xls]
2021-11-13 0.55-pre
    Change Encoder detecting to table-based.
2021-11-14 0.55-pre3
    Fix de-chatter cap. values to 22nF -> 100nF
    [LrTMAX.BOM.csv, LrTMAX.sch]
2021-12-06 0.55-5
    Fix USBD_SELF_POWER to 0
    [main.c]
2021-12-15 0.55-10
    Function assign modification Scene0 A6,A7 as quick development.
    Revert back 'connect indication' by setup packet id received.
    [LrTMAX.BOM.csv]
2021-12-16 0.55-11
    Fix optimize level = 2
    [LrTMAX.BOM.csv]
2021-12-31 0.56-3
    Fix CC channels per scene for 10 -> 8
    [main.h]
2021-12-31 0.56-4
    Fix Key Assignments & LED colors.
    [key_define.c]
2021-12-31 0.57
    Version Feed.
    It seems to fixed for #8 issue.
    [main.h]
2022-01-04 0.57-1
    Fix CC channel offset 40 -> 64
    Now LrTMAX act as keyboard that has no velocity support.
    [key_define.c, main.c, main.h]
2022-01-08 0.57-4
    invalidate MIDI_DataRx() for fix MIDI_CC_Value() destruction by
    invalid index.
    [main.c]
2022-01-12 0.58
    Fixed issue #8 totally.
    [key_define.c]
2022-02-01 0.58-3
    modify case
    [Case.FCStd, Case.stl]
2022-03-01 0.59-9
    Fix KEYSCAN definition.
    [LrCommon.h]
2022-03-04 0.59-10
    refine key_define.c comments.
    fix variable scope.
    [Case.FCStd, Case.stl]
2022-03-04 0.59-11
    move LED_SetScene() to led.c
2022-03-05 0.59-15
    LrTMAX case ordered.
    [Case.FCStd, Case.stl]
2022-03-08 0.59-16
    Case-noscrew added.
    [Case-noscrew.FCStd, Case-noscrew.stl]
2022-05-19 0.59-18
    experimental fix for #11 issue.
    [main.c]
2022-07-11 0.59-22
    reverse de-chattter cap. to 22n
    [KNOB1.stl, LrTMAX.BOM.csv, LrTMAX.sch]
2022-07-13 0.60-pre0
    Enable TIM15 for de-chatter.
2022-07-15 0.60-pre3
    TIM15 based de-chattering.
    Fix NeoPixel RESET wait.
    Change TIM14 as 'one pulse mode'
    [STM32F072.xlsx]
2022-07-16 0.60-pre4
    Refine stm32f0_it.c structure
    Rename macro symbol name for timers
2022-09-24 Mechanical de-chatter first implementation
2022-09-25 Applies de-chatter logic to all axis.
2022-09-26 0.61-3
    Modifies de-chatter logic.
2023-01-28 0.62-00
    add kicad 6.0 pattern to LrTMAX.l4pb/gitignore
2023-01-30 0.62-00.12cc
    Modify "BOOT0" connection on PCB as "1.2cc"
    [LrTMAX.BOM.csv, LrTMAX.kicad_pcb, LrTMAX.sch]
2023-02-04 0.62-1
    Add 'Reset LrTMAX' functionality with key combination.
    [main.c, main.h]
2023-03-11 0.62-4
    Change MIDI note velocity to 127 from 64.
2023-03-12 0.62-6
    Version skipping same as 0.62-3
    [main.c]
2023-03-13 0.62-11
    Again Note velocity set to 127 from 64.
2023-03-22 replace SWD to 10p header
    [LrTMAX.kicad_pcb, LrTMAX.kicad_sch]
2023-03-23 Added DFU DIP Switch.
    [LrTMAX.kicad_pcb, LrTMAX.kicad_sch]
2023-03-26 Refine pattern.
    [LrTMAX.kicad_pcb]
2023-03-26 Flex wire hall refined
    [LrTMAX.kicad_pcb, LrTMAX.kicad_sch]
2023-03-26 Fix BOM .csv file.
    [LrTMAX.BOM.csv, LrTMAX.sch]
2023-04-04 modify PCB BOM for JLCPCB Asslembly order(just a test)
    [LrTMAX.BOM.csv]
2023-04-15 0.63-2
    Just alignment fix after LrTMAX_l4pb_1.2d is marged.
    [key_define.c, led.c, main.c]
2023-05-09 Split out as submodules for *.4lpb *.panel *.case *.knob
    [Case-noscrew.FCStd, Case-noscrew.stl, Case.FCStd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]
2023-05-13 Split out Documents
    [STM32F072.xlsx, WS2812C-2020.xls]
2023-07-03 0.65-22
    Fix MIDI_DataRx() to store for MIDI_CC_VALUE[] collectly.
    [LrCommon.h]
2023-07-05 EmulateMIDI.c を更新
2023-07-05 LrCommon.h を更新
2023-07-05 key_define.h を更新
2023-07-05 0.66-pre2
    Adjust encoder's Note numbers same as CC channel numbers.
2023-07-05 0.66-pre3
    fix Note number for encoder push.
    [EmulateMIDI.c, LrCommon.h]
2023-07-22 0.66-8
    LrTMAX.4lpb board order
2023-07-24 0.67-2
    fix CW/CCW for Inc/Dec.
    [EmulateMIDI.c]
2023-07-28 0.67-6
    fix build environments
    [EmulateMIDI.c]
2023-07-29 0.67-7
    Fixed encoder ISRs to chatter does not make changes any internal states.
2023-07-30 0.67-11
    Collects TIM15 de-chattering period to 2mS.
2023-08-01 0.68-pre2
    After generate codes by STM32CubeMX in STM32CubeIDE
2023-08-07 0.67-14
    add enc_prev[] initialization by pin conditions.
2023-08-10 0.68-pre6
    encoder detection
2023-08-11 0.67-17
    Moved Encoder Initialization as ENC_Init() on stm32f0xx_it.c
2023-08-11 0.68-pre8
    OK with Encoder move to MIDI message send.
2023-08-11 0.68-pre9
    Fix for duplicated MIDI messages from encoder.
    [EmulateMIDI.c]
2023-08-12 0.68-pre12
    fix only typos.
    [EmulateMIDI.c, main.c]
2023-08-12 0.68-pre13
    Adjust Encoder Timer Interval to 4.25mSec.
2023-08-13 0.68-1
    Adjust rotary encoder timer to 2mSec.
2023-08-28 0.59-2
    fix doxygen comments only
    [led.h, main.c, prof_define.c]
2023-09-02 0.69-9
    Modify to Pick initial encoder condition on USB connect.
2023-09-06 0.69-13
    modify LED pattern
2023-09-08 0.69-14
    Add LED color
2023-09-08 0.69-15
    ADjust LED colors.
2023-09-11 0.69-16
    Add filess for STM32 VSCode extention.
2023-09-14 0.68-18
    Modified STM32 VScode extension settings.
2024-01-11 0.69-21
    Modify to use HAL function in LED DMA initialize.
2024-03-13 0.70-pre2
    Change LED initialize order to top.
2024-06-15 0.70-2
    moved STM32 firmware to F0_V1.11.5
2024-06-28 0.70-3
    Fix ioc typos
    [LrTMAX.ioc]
2024-07-14 0.71
    Scene timer added.
    If no touch with swith/rotator 1 hour, Scene back to SCENE0.
2024-07-14 0.71-1
    Fix pressing Scene0 button on software.
    [EmulateMIDI.c, LrCommon.h]
2024-08-20 Update stm32f0xx_hal_msp.c part3
2024-08-22 0.71-14
    Change linker script with genarated by newer STM32CubeIDE.
2024-08-22 0.71-15
    Fix for reduce regenatete work.
    [main.c]
2024-08-23 0.71-16
    Fix for reduce regenatete work.(part2)
    [main.c]
2024-08-24 0.71-17
    follow STM32CubeIDE code generation.
2024-08-25 0.71
    Fix DFU can't launch by key combination at powering.
    [main.c, main.h]
2024-08-25 0.71-20
    Fix comment only.
    [main.c]
2024-09-07 0.72-pre2b
    Fix for comments.
    [Jump2System.c, opr_define.c]
2024-10-26 0.72-8
    Fix unintentional D31 flash by any encoder push.
    [EmulateMIDI.c]
2024-11-02 0.72-9
    Fix LEDs does not flash.
    [EmulateMIDI.c]
2025-04-19 0.72-12
    Extend SSD1306 power-up time wait.
2025-10-25 0.73-pre
    change rotary encoder scan rate 1666 -> 2000us
2025-11-14 0.73-pre2
    Added de-chatter timer for encoders.
2025-11-15 0.73
    encoder chatter reduction by timer
    operation detected within 50ms from prev. MIDI send. that is skipped.
    [LrTMAX.ioc, main.h]

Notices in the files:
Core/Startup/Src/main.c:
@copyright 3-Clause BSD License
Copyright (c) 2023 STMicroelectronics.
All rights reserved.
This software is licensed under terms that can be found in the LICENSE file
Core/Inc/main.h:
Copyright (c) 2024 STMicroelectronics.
